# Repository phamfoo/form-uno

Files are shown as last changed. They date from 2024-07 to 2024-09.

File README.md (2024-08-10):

# Form Uno
> Gasket mounted 5x12 column staggered keyboard

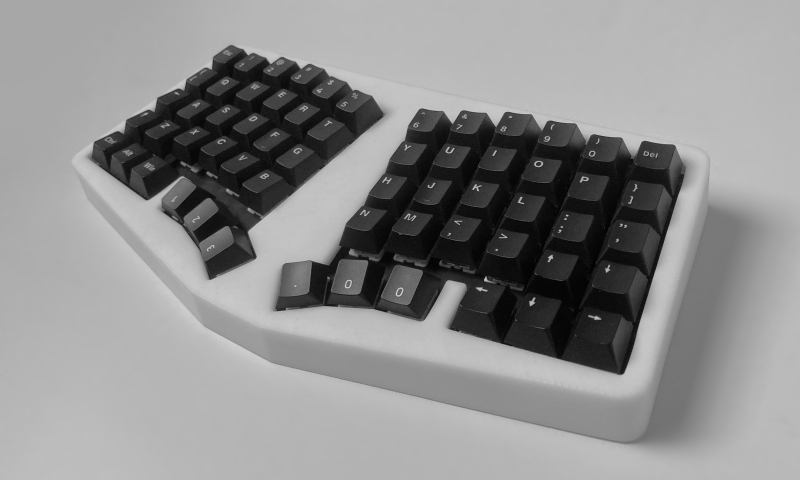
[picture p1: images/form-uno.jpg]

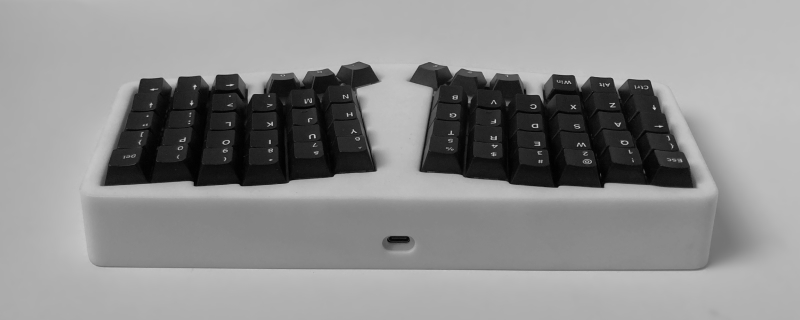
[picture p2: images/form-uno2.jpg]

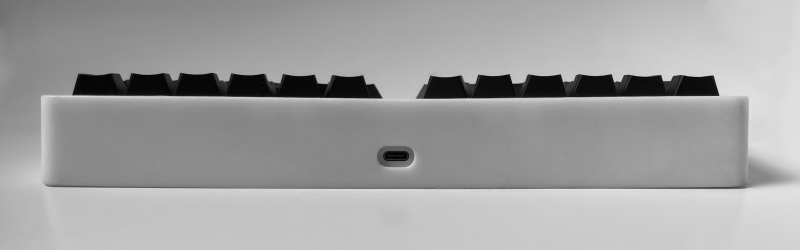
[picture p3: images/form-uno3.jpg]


## Introduction
I designed this board with a few goals in mind:

### Ergonomic
The layout is based on the corne/cornelius by [foostan](https://github.com/foostan), with some adjustments:
- Unsplit.
- Number row.
- Options for dedicated arrow keys.

### Fully featured
It also comes with the neat features that you'd find in custom mechanical keyboards:

- Gasket-mounted.
- Hotswap PCB + daughterboard.
- Clean and minimal design.

### Easy to build
- Powered by an [RP2040 Tiny](https://www.waveshare.com/rp2040-tiny.htm) and [all the other parts](build) can be easily sourced.
- No tiny SMD components required!

## Build guide
See [build](/build)

## Thanks
- [JLCPCB](https://jlcpcb.com/?from=see) for providing the keyboard plate, 3D printed case, and PCB for this project. If you're looking to build your own board, I highly recommend their services.
- [foostan](https://github.com/foostan) for creating the corne/cornelius, which inspired this project in the first place.

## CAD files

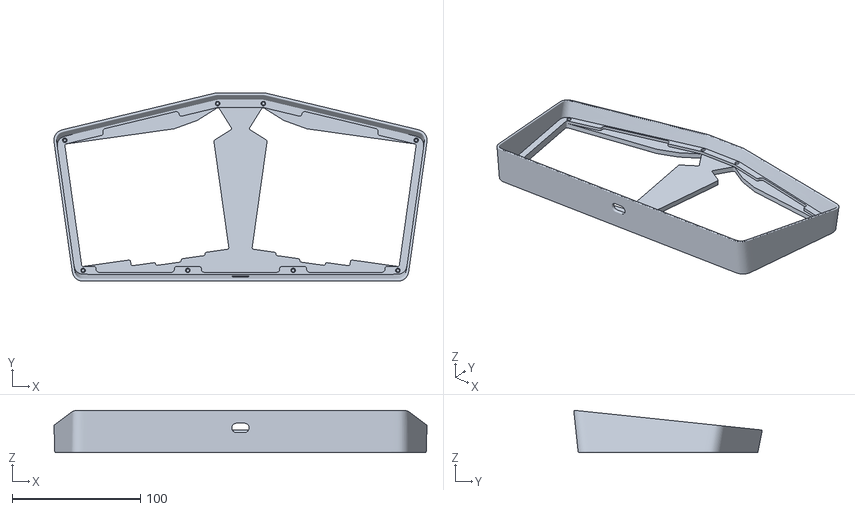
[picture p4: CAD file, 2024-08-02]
build/case/resin-top-case-no-blockers.stl
290.4 x 146.7 x 33.0

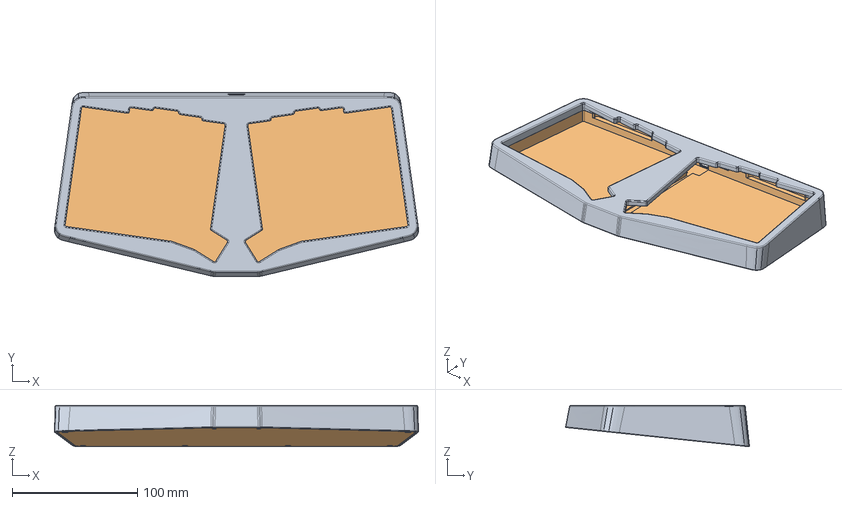
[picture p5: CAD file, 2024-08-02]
src/case/resin-case-no-blockers.step
290.4 x 146.7 x 33.0 mm

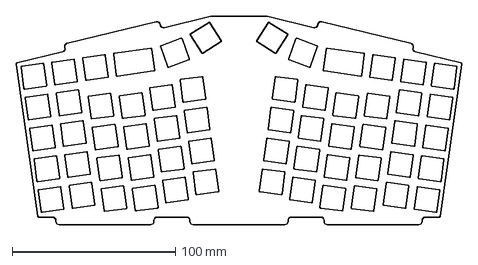
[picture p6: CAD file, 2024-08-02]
src/plate.dxf
272.5 x 127.4 mm

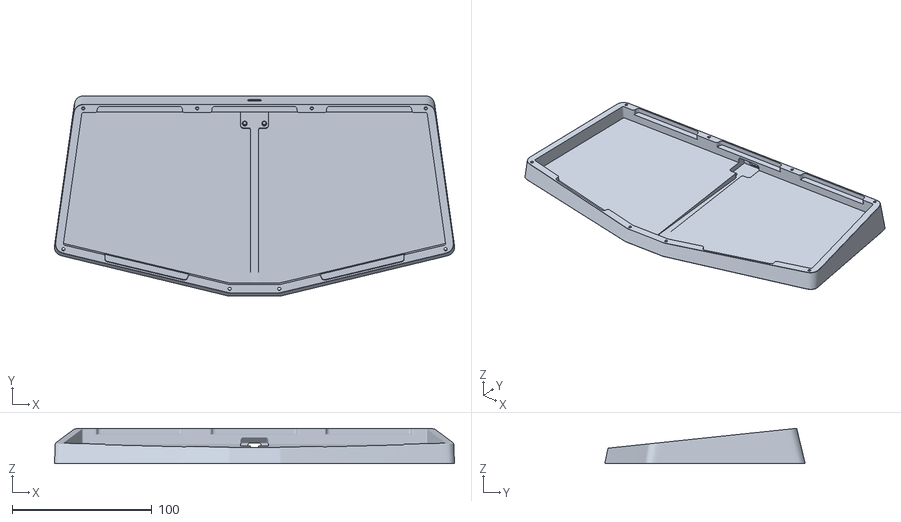
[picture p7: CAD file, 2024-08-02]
build/case/resin-bottom-case.stl
286.3 x 143.3 x 25.2

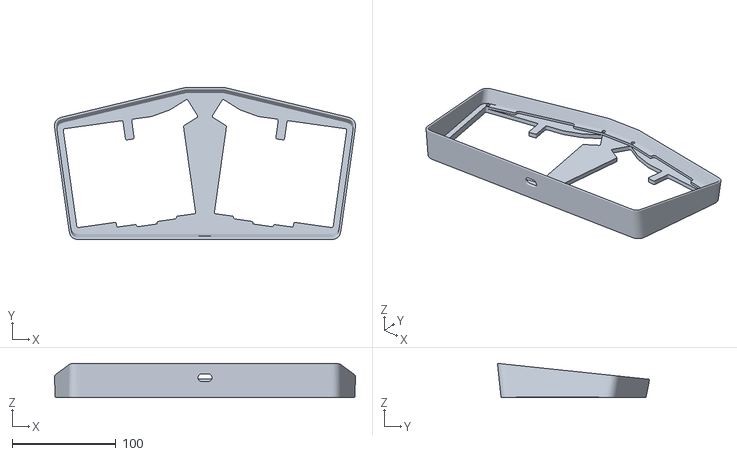
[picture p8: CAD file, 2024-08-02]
build/case/resin-top-case.stl
290.4 x 146.7 x 33.0

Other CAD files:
src/case/fdm-case.step
src/case/resin-case.step
build/case/fdm-top-case-no-blockers.stl
src/case/fdm-case-no-blockers.step
build/case/fdm-bottom-case.stl
build/case/fdm-top-case.stl

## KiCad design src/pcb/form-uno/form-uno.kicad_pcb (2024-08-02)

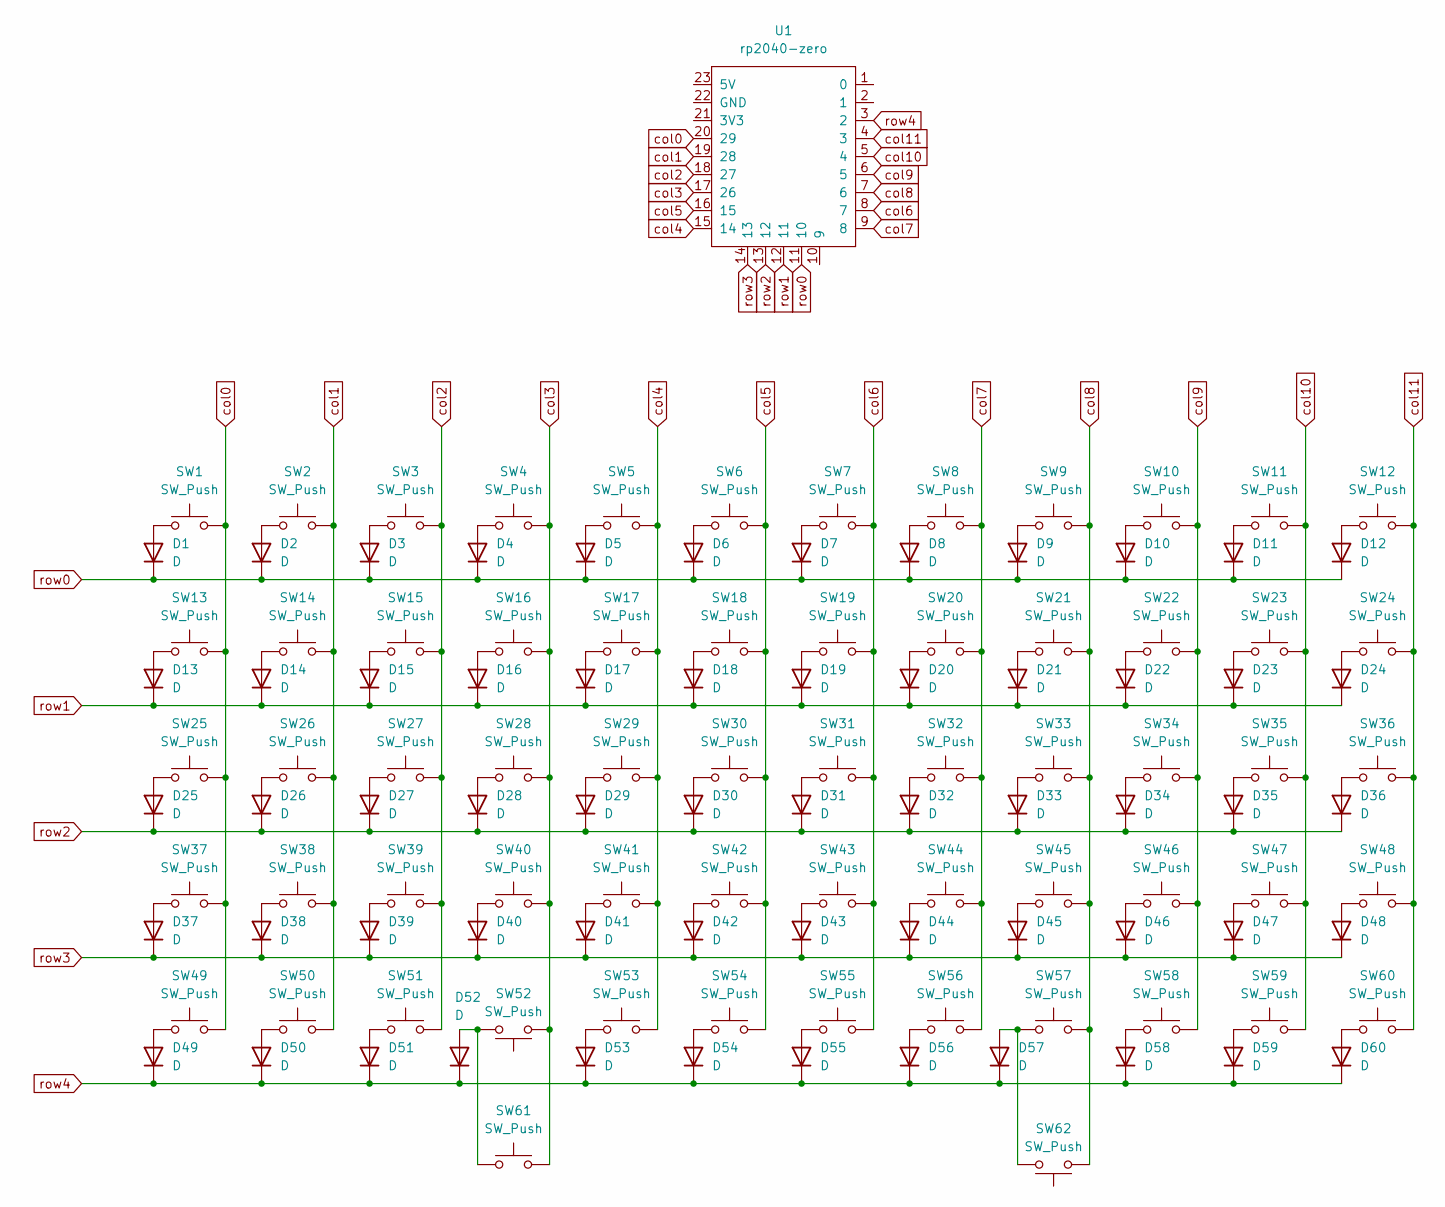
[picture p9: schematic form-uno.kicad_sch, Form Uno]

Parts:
D1, D2, D3, D4, D5, D6, D7, D8, D9, D10, D11, D12, D13, D14, D15, D16, D17, D18, D19, D20, D21, D22, D23, D24, D25, D26, D27, D28, D29, D30, D31, D32, D33, D34, D35, D36, D37, D38, D39, D40, D41, D42, D43, D44, D45, D46, D47, D48, D49, D50, D51, D52, D53, D54, D55, D56, D57, D58, D59, D60: D; D3_TH_SMD_v2
SW1, SW2, SW3, SW4, SW5, SW6, SW7, SW8, SW9, SW10, SW11, SW12, SW13, SW14, SW15, SW16, SW17, SW18, SW19, SW20, SW21, SW22, SW23, SW24, SW25, SW26, SW27, SW28, SW29, SW30, SW31, SW32, SW33, SW34, SW35, SW36, SW37, SW38, SW39, SW40, SW41, SW42, SW43, SW44, SW45, SW46, SW47, SW48, SW49, SW50, SW51, SW52, SW53, SW54, SW55, SW56, SW57, SW58, SW59, SW60, SW61, SW62: SW_Push; SW_MX_HS_CPG151101S11_1u
U1: rp2040-zero; rp2040-tiny

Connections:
unnamed: D1.2 (A), SW1.1
unnamed: D2.2 (A), SW2.1
unnamed: D3.2 (A), SW3.1
unnamed: D4.2 (A), SW4.1
unnamed: D5.2 (A), SW5.1
unnamed: D6.2 (A), SW6.1
unnamed: D7.2 (A), SW7.1
unnamed: D8.2 (A), SW8.1
unnamed: D9.2 (A), SW9.1
unnamed: D10.2 (A), SW10.1
unnamed: D11.2 (A), SW11.1
unnamed: D12.2 (A), SW12.1
unnamed: D13.2 (A), SW13.1
unnamed: D14.2 (A), SW14.1
unnamed: D15.2 (A), SW15.1
unnamed: D16.2 (A), SW16.1
unnamed: D17.2 (A), SW17.1
unnamed: D18.2 (A), SW18.1
unnamed: D19.2 (A), SW19.1
unnamed: D20.2 (A), SW20.1
unnamed: D21.2 (A), SW21.1
unnamed: D22.2 (A), SW22.1
unnamed: D23.2 (A), SW23.1
unnamed: D24.2 (A), SW24.1
unnamed: D25.2 (A), SW25.1
unnamed: D26.2 (A), SW26.1
unnamed: D27.2 (A), SW27.1
unnamed: D28.2 (A), SW28.1
unnamed: D29.2 (A), SW29.1
unnamed: D30.2 (A), SW30.1
unnamed: D31.2 (A), SW31.1
unnamed: D32.2 (A), SW32.1
unnamed: D33.2 (A), SW33.1
unnamed: D34.2 (A), SW34.1
unnamed: D35.2 (A), SW35.1
unnamed: D36.2 (A), SW36.1
unnamed: D37.2 (A), SW37.1
unnamed: D38.2 (A), SW38.1
unnamed: D39.2 (A), SW39.1
unnamed: D40.2 (A), SW40.1
unnamed: D41.2 (A), SW41.1
unnamed: D42.2 (A), SW42.1
unnamed: D43.2 (A), SW43.1
unnamed: D44.2 (A), SW44.1
unnamed: D45.2 (A), SW45.1
unnamed: D46.2 (A), SW46.1
unnamed: D47.2 (A), SW47.1
unnamed: D48.2 (A), SW48.1
unnamed: D49.2 (A), SW49.1
unnamed: D50.2 (A), SW50.1
unnamed: D51.2 (A), SW51.1
unnamed: D52.2 (A), SW52.2, SW61.1
unnamed: D53.2 (A), SW53.1
unnamed: D54.2 (A), SW54.1
unnamed: D55.2 (A), SW55.1
unnamed: D56.2 (A), SW56.1
unnamed: D57.2 (A), SW57.1, SW62.2
unnamed: D58.2 (A), SW58.1
unnamed: D59.2 (A), SW59.1
unnamed: D60.2 (A), SW60.1
col0: SW1.2, SW13.2, SW25.2, SW37.2, SW49.2, U1.20 (29)
col1: SW2.2, SW14.2, SW26.2, SW38.2, SW50.2, U1.19 (28)
col2: SW3.2, SW15.2, SW27.2, SW39.2, SW51.2, U1.18 (27)
col3: SW4.2, SW16.2, SW28.2, SW40.2, SW52.1, SW61.2, U1.17 (26)
col4: SW5.2, SW17.2, SW29.2, SW41.2, SW53.2, U1.15 (14)
col5: SW6.2, SW18.2, SW30.2, SW42.2, SW54.2, U1.16 (15)
col6: SW7.2, SW19.2, SW31.2, SW43.2, SW55.2, U1.8 (7)
col7: SW8.2, SW20.2, SW32.2, SW44.2, SW56.2, U1.9 (8)
col8: SW9.2, SW21.2, SW33.2, SW45.2, SW57.2, SW62.1, U1.7 (6)
col9: SW10.2, SW22.2, SW34.2, SW46.2, SW58.2, U1.6 (5)
col10: SW11.2, SW23.2, SW35.2, SW47.2, SW59.2, U1.5 (4)
col11: SW12.2, SW24.2, SW36.2, SW48.2, SW60.2, U1.4 (3)
row0: D1.1 (K), D2.1 (K), D3.1 (K), D4.1 (K), D5.1 (K), D6.1 (K), D7.1 (K), D8.1 (K), D9.1 (K), D10.1 (K), D11.1 (K), D12.1 (K), U1.11 (10)
row1: D13.1 (K), D14.1 (K), D15.1 (K), D16.1 (K), D17.1 (K), D18.1 (K), D19.1 (K), D20.1 (K), D21.1 (K), D22.1 (K), D23.1 (K), D24.1 (K), U1.12 (11)
row2: D25.1 (K), D26.1 (K), D27.1 (K), D28.1 (K), D29.1 (K), D30.1 (K), D31.1 (K), D32.1 (K), D33.1 (K), D34.1 (K), D35.1 (K), D36.1 (K), U1.13 (12)
row3: D37.1 (K), D38.1 (K), D39.1 (K), D40.1 (K), D41.1 (K), D42.1 (K), D43.1 (K), D44.1 (K), D45.1 (K), D46.1 (K), D47.1 (K), D48.1 (K), U1.14 (13)
row4: D49.1 (K), D50.1 (K), D51.1 (K), D52.1 (K), D53.1 (K), D54.1 (K), D55.1 (K), D56.1 (K), D57.1 (K), D58.1 (K), D59.1 (K), D60.1 (K), U1.3 (2)

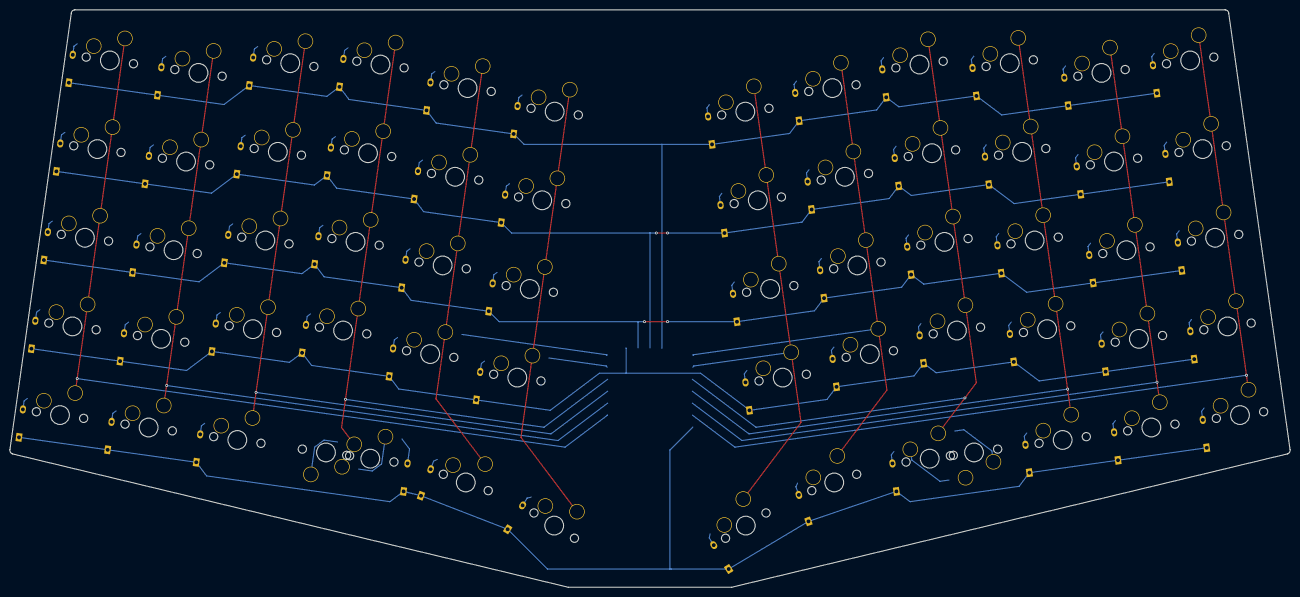
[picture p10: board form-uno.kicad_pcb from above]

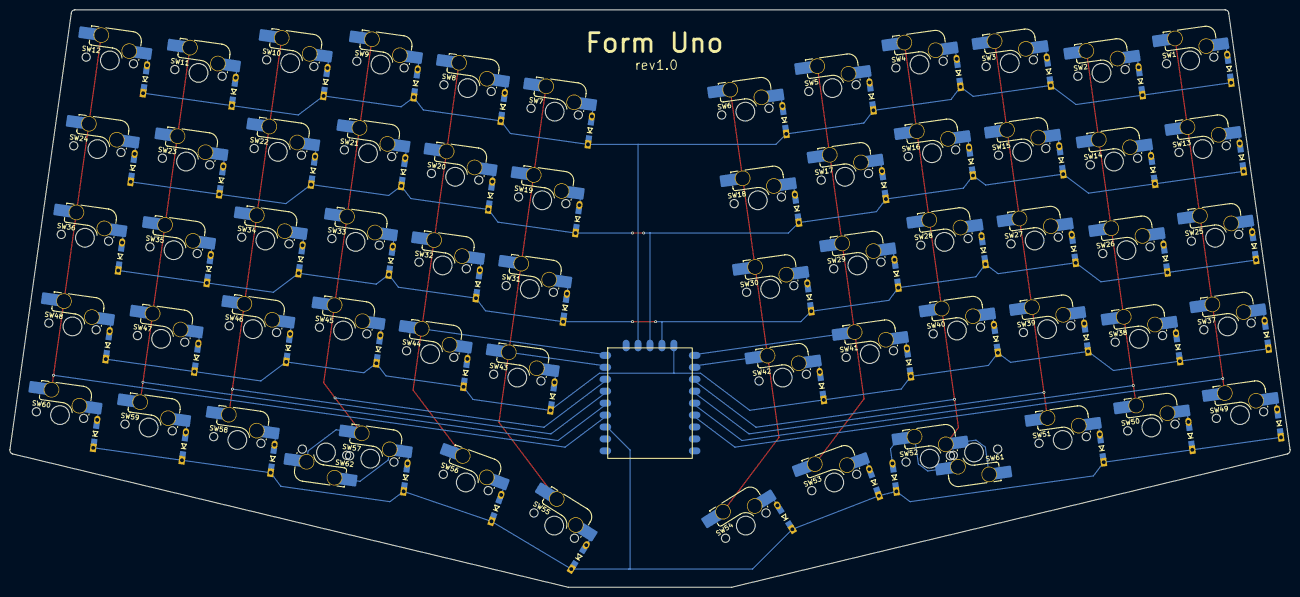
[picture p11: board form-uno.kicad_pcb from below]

Board: 2 copper layers, 272.4 x 122.9 mm, 123 parts (123 on the bottom side), 77 nets.

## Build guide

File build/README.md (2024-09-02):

# Build Guide
Please open an issue if you have any questions.

# The parts
I've included links to purchase some of the parts needed for this build. They're all non-affiliate links.

- [3D printed case](./case)
- [RP2040 Tiny](https://www.waveshare.com/rp2040-tiny.htm)
- [PCB](./pcb-gerbers.zip)
- 10 x M2 heat set inserts
    - [These inserts](https://www.aliexpress.com/item/1005003582355741.html) should work.
    - Select these options: `M2(OD 3.5mm)` and `Length 3mm`.
- 10 x M2x6mm screws
- 62 x kailh hotswap sockets
- 60 x 1N4148 diodes
    - The PCB supports both through hole and SMD diodes.
- [Plate](./plate-gerbers.zip)
- 10 x poron gaskets
    - If you want the gaskets to fit the case perfectly, buy these [D65 gaskets](https://www.aliexpress.com/item/1005004488920878.html).
    - Smaller gaskets should also work, as long as they provide enough tension to securely hold the plate in place. **Just make sure the gaskets are 3mm thick.**

# Build the board
## Firmware
This repo doesn't include the firmware for the board, so you'll need to build it yourself using [QMK](https://github.com/qmk/qmk_firmware).

```json
"matrix_pins": {
    "cols": ["GP29", "GP28", "GP27", "GP26", "GP14", "GP15", "GP7", "GP8", "GP6", "GP5", "GP4", "GP3"],
    "rows": ["GP10", "GP11", "GP12", "GP13", "GP2"]
},
```

## Prepare the case
### Print the case
There are a few options for the case. You can choose either the FDM case or the resin case. They are almost identical. The only difference is that the holes for the threaded inserts are larger on the resin case.

There's also the option to print the top case with or without blockers. By default, each half has three thumb keys, with a blocker separating the bottom keys.

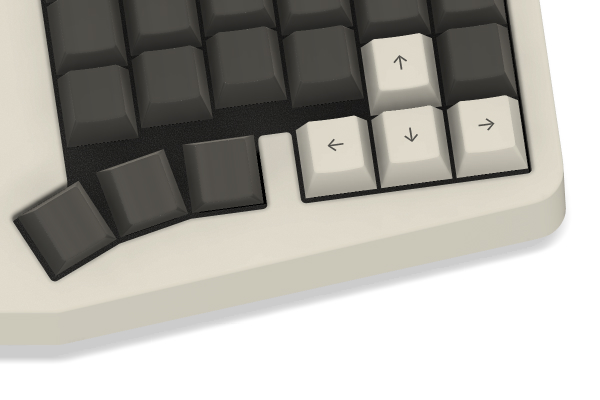
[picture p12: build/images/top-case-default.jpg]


Without the blocker, the innermost thumb key can be moved to the right.

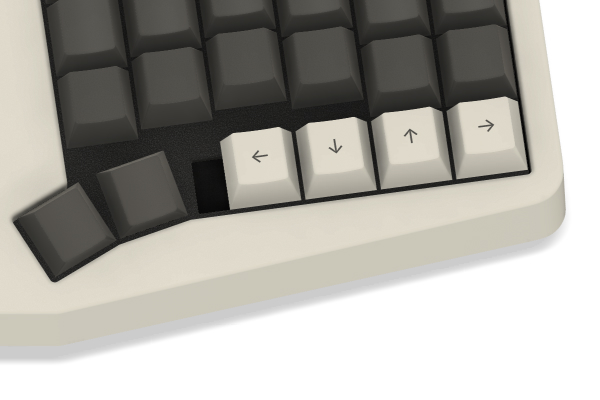
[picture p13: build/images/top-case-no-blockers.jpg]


### Install threaded inserts

Once the case is printed, install the threaded inserts. You'll need to install 8 on the top case and 2 on the bottom case, where the daughterboard is mounted.

## Solder the parts
Start by soldering the hotswap sockets and the diodes. I recommend using through-hole diodes, as they are much easier to work with than the SMD ones.

Next, solder the RP2040 Tiny to the PCB.

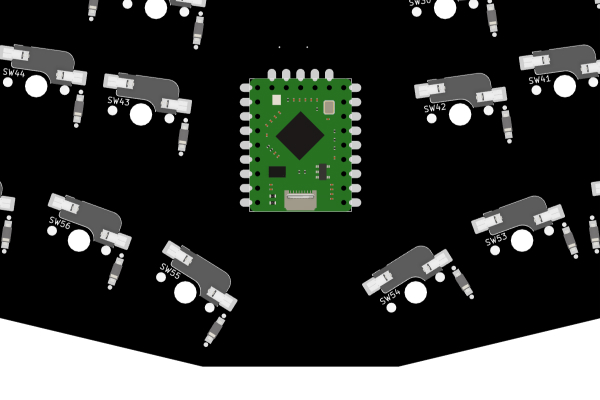
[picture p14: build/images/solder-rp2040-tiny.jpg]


If you're unfamiliar with soldering castellated holes, check out [this video](https://www.youtube.com/watch?v=rGvvwXrv310).

## Install the switches
The board doesn't come with standoffs, so it might be a little tricky to install the switches. Watch [this video](https://www.youtube.com/watch?v=MtzzKFZqiPw&t=303s) if you're not sure how to do it properly.

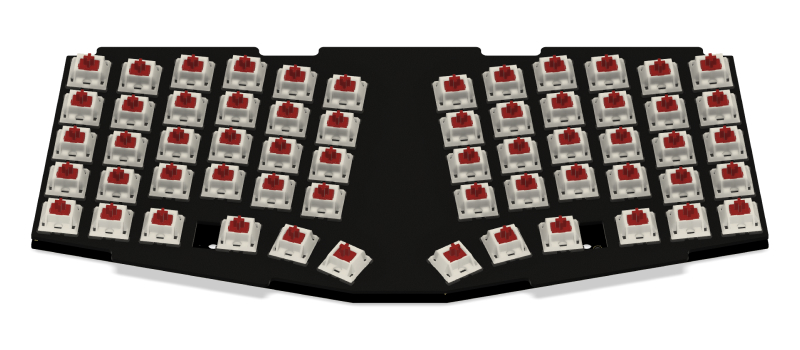
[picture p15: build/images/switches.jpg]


I also highly recommend performing the PE foam mod and tape mod at this step. From my experience, these two mods greatly improve the sound of the board.

## Install the gaskets

Install the gaskets (4x60mm) on the top and bottom case (there are 10 in total).

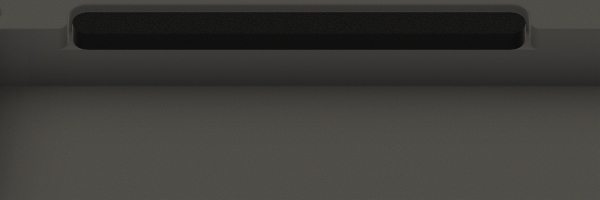
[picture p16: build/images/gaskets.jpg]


Smaller gaskets should also work.

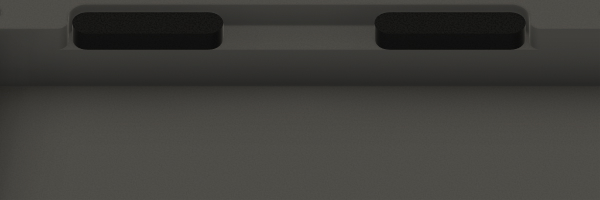
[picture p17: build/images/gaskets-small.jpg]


## Assemble the board

Screw in the daughter board.

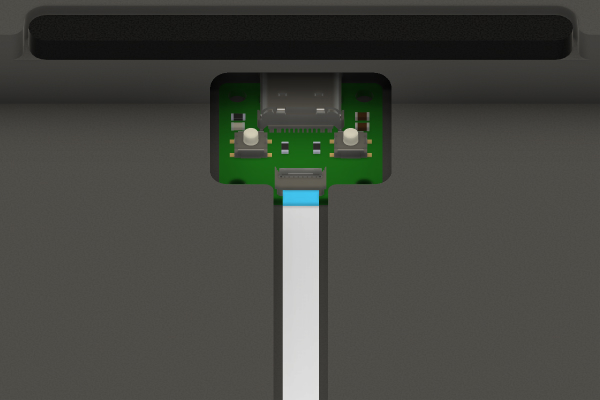
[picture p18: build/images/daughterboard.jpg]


Connect the daughterboard to the PCB.

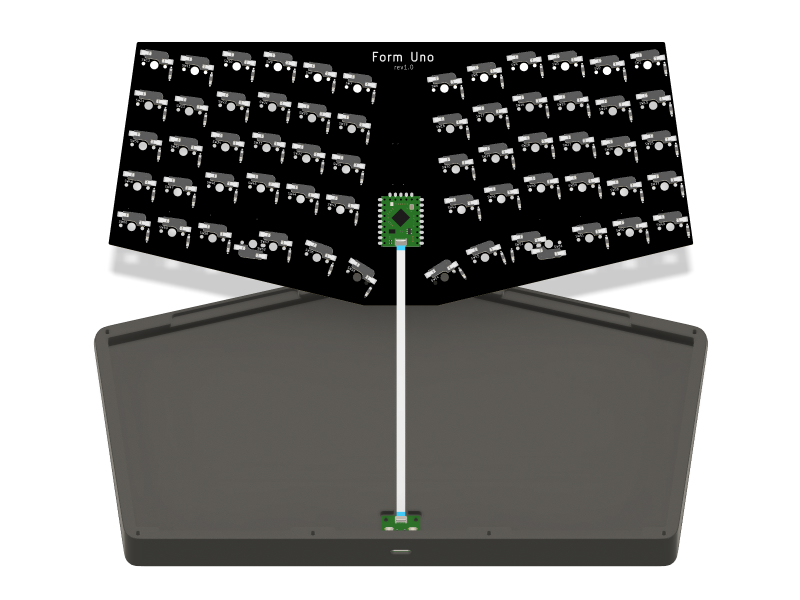
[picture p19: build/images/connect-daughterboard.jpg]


Place everything on top of the bottom case.

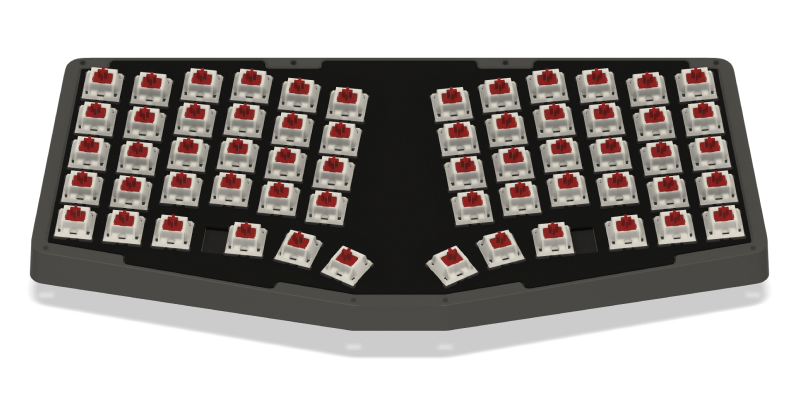
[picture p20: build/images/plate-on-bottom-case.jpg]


Screw in the top case and put on the keycaps. You're done!

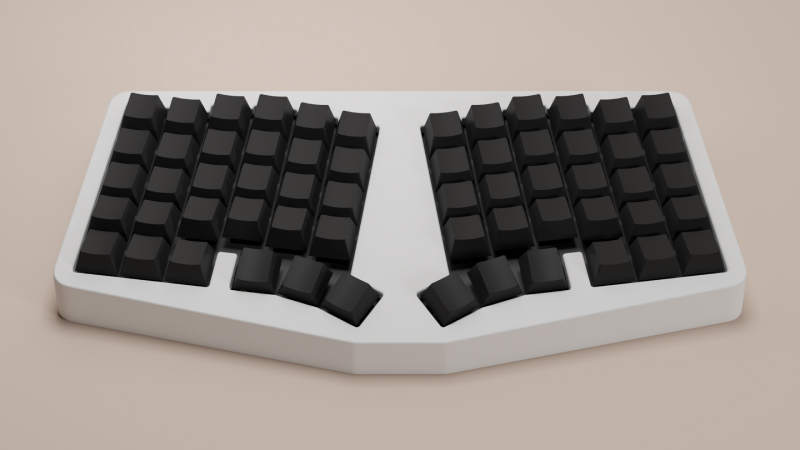
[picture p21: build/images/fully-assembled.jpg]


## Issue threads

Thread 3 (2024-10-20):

Question: PCB & Plate Thickness

keb-web, 2024-10-20:
What thickness do you recommend when manufacturing the PCB and plate?

phamfoo, 2024-10-21:
1.6mm for both pcb and plate.

Closed 2024-10-21.

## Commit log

2024-06-29 Add schematic and position the keys
    [form-uno.kicad_pcb, form-uno.kicad_sch]
2024-06-29 Route the board matrix
    [form-uno.kicad_pcb, form-uno.kicad_sch]
2024-07-04 Route the rows and cols to microcontroller
    [form-uno.kicad_pcb, form-uno.kicad_sch]
2024-07-04 Add rounded corners
    [form-uno.kicad_pcb]
2024-07-27 Update rp2040 tiny footprint
    [form-uno.kicad_pcb, form-uno.kicad_sch]
2024-08-02 Set pcb revision
    [form-uno.kicad_pcb, form-uno.kicad_sch]
2024-08-02 Add build files
    [fdm-bottom-case.stl, fdm-case-no-blockers.step, fdm-case.step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]
